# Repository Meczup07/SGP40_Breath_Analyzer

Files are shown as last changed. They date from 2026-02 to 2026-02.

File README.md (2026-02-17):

# 🌬️ SGP40-AlcSense: Ultra-Compact IoT Breathalyzer

  

**SGP40-AlcSense** is a portable, USB-C rechargeable breath analysis device (Breathalyzer) measuring only **30mm x 20mm**.

This project combines advanced **Sensirion SGP40 VOC** sensor technology with the power of the **Nordic nRF52832** SoC to measure alcohol intensity (VOC Index) and provide instant visual feedback via an RGB LED or transmit data to a mobile app via Bluetooth Low Energy (BLE).

---

## 📸 Project Images





---

## 🌟 Key Features

* **Ultra-Compact Design:** Keychain-sized (30x20mm) 2-layer PCB.
* **High-Sensitivity Detection:** Sensirion SGP40 MOx sensor sensitive to Alcohol (Ethanol) vapor.
* **Wireless Connectivity:** Bluetooth 5.0 (BLE) support via nRF52832 (ARM Cortex-M4F).
* **Visual Feedback:** RGB LED changes color based on ambient alcohol levels (Green/Yellow/Red).
* **Power Management:**
    * Integrated Li-Po Battery Charging Circuit (MCP73831).
    * DC-DC Buck Converter mode for low power consumption.
    * USB Type-C Charging Input.
* **RF Design:** Johanson 2450AT18A Chip Antenna with impedance matching (Pi-Network).

---

## 🛠️ Hardware Specifications

The project is built on the following core components:

| Component | Model | Description |
| :--- | :--- | :--- |
| **MCU** | `nRF52832-QFAA` | Main Processor & BLE Module. |
| **Sensor** | `SGP40-D-R4` | Digital VOC (Volatile Organic Compound) Sensor. |
| **Charger IC** | `MCP73831` | Li-Ion/Li-Po Charge Controller (CC/CV). |
| **Regulator** | `XC6206` | 3.3V LDO Voltage Regulator. |
| **Antenna** | `2450AT18A0110` | 2.4GHz SMD Chip Antenna. |
| **LED** | `XL-1608RGBC` | 0603 SMD RGB LED (Common Cathode). |
| **Connector** | `USB-C 16-Pin` | Power input & Charging. |

---

## 📐 Schematic & PCB Design

- **PCB Size:** 30mm x 20mm
- **Layers:** 2-layer PCB
- **Thickness:** 1.6mm
- **Design Tool:** Altium Designer / KiCAD

Full schematic and Gerber files are available in the [hardware/](hardware/) directory.

---

## 📌 Pinout Map

Pin definitions for firmware development:
```cpp
// RGB LED Connections (Common Cathode - Active LOW)
#define PIN_LED_RED    8   // P0.08
#define PIN_LED_GREEN  9   // P0.09
#define PIN_LED_BLUE   10  // P0.10

// I2C (SGP40 Sensor)
#define PIN_SDA        6   // P0.06 (check your schematic!)
#define PIN_SCL        7   // P0.07 (check your schematic!)

// SWD Programming Interface
#define PIN_SWDCLK     25  // P0.25
#define PIN_SWDIO      26  // P0.26

// Battery Monitoring (Optional)
#define PIN_VBAT_SENSE 3   // P0.03 (ADC Channel)
```

⚠️ **Important:** Verify pin assignments against your actual schematic before programming!

---

## 🚦 LED Status Indicators

The RGB LED provides real-time feedback on alcohol detection levels:

| VOC Index | LED Color | Status | Description |
|---|---|---|---|
| **0 - 100** | 🟢 Green | Safe | No alcohol detected |
| **100 - 250** | 🟡 Yellow | Moderate | Low alcohol level |
| **250+** | 🔴 Red | High | Dangerous alcohol level |

---

## 🔧 Software Development

### Prerequisites

Before building the firmware, you'll need:

1. **Segger Embedded Studio** (v7.22 or newer) - [Download](https://www.segger.com/downloads/embedded-studio/)
2. **Nordic nRF5 SDK v17.1.0** - [Download](https://www.nordicsemi.com/Products/Development-software/nrf5-sdk/download)
3. **J-Link Debugger** or **ST-Link V2** (for SWD programming)

---

### 📦 Step 1: Install nRF5 SDK

1. Download **nRF5 SDK v17.1.0** from Nordic's website:
```
   https://www.nordicsemi.com/Products/Development-software/nrf5-sdk/download
```

2. Extract the SDK to a convenient location:
   - **Windows:** `C:\nRF5_SDK_17.1.0`
   - **macOS/Linux:** `~/nRF5_SDK_17.1.0`

3. **Important:** Do NOT rename the SDK folder. Keep it as `nRF5_SDK_17.1.0`.

---

### 📥 Step 2: Clone This Repository
```bash
git clone https://github.com/Meczup07/SGP40_Breath_Analyzer.git
cd SGP40_Breath_Analyzer
```

---

### 🔨 Step 3: Build the Firmware

#### Option A: Using Segger Embedded Studio (Recommended)

1. Open Segger Embedded Studio

2. Navigate to the SDK example template:
```
   C:\nRF5_SDK_17.1.0\examples\ble_peripheral\ble_app_template\pca10040\s132\ses\
```

3. Open the project file:
```
   ble_app_template_pca10040_s132.emProject
```

4. In the **Project Explorer** (left panel), locate:
```
   Application → main.c
```

5. Replace the contents of `main.c` with the code from this repository's `src/main.c`

6. **Build the project:**
   - Press `F7` or go to **Build → Build Solution**

7. **Connect your J-Link debugger** to the SWD pins:
```
   J-Link    →    nRF52832
   --------       ---------
   SWDCLK   →    P0.25
   SWDIO    →    P0.26
   VDD      →    3.3V
   GND      →    GND
```

8. **Flash the firmware:**
   - Press `F5` or go to **Debug → Go**

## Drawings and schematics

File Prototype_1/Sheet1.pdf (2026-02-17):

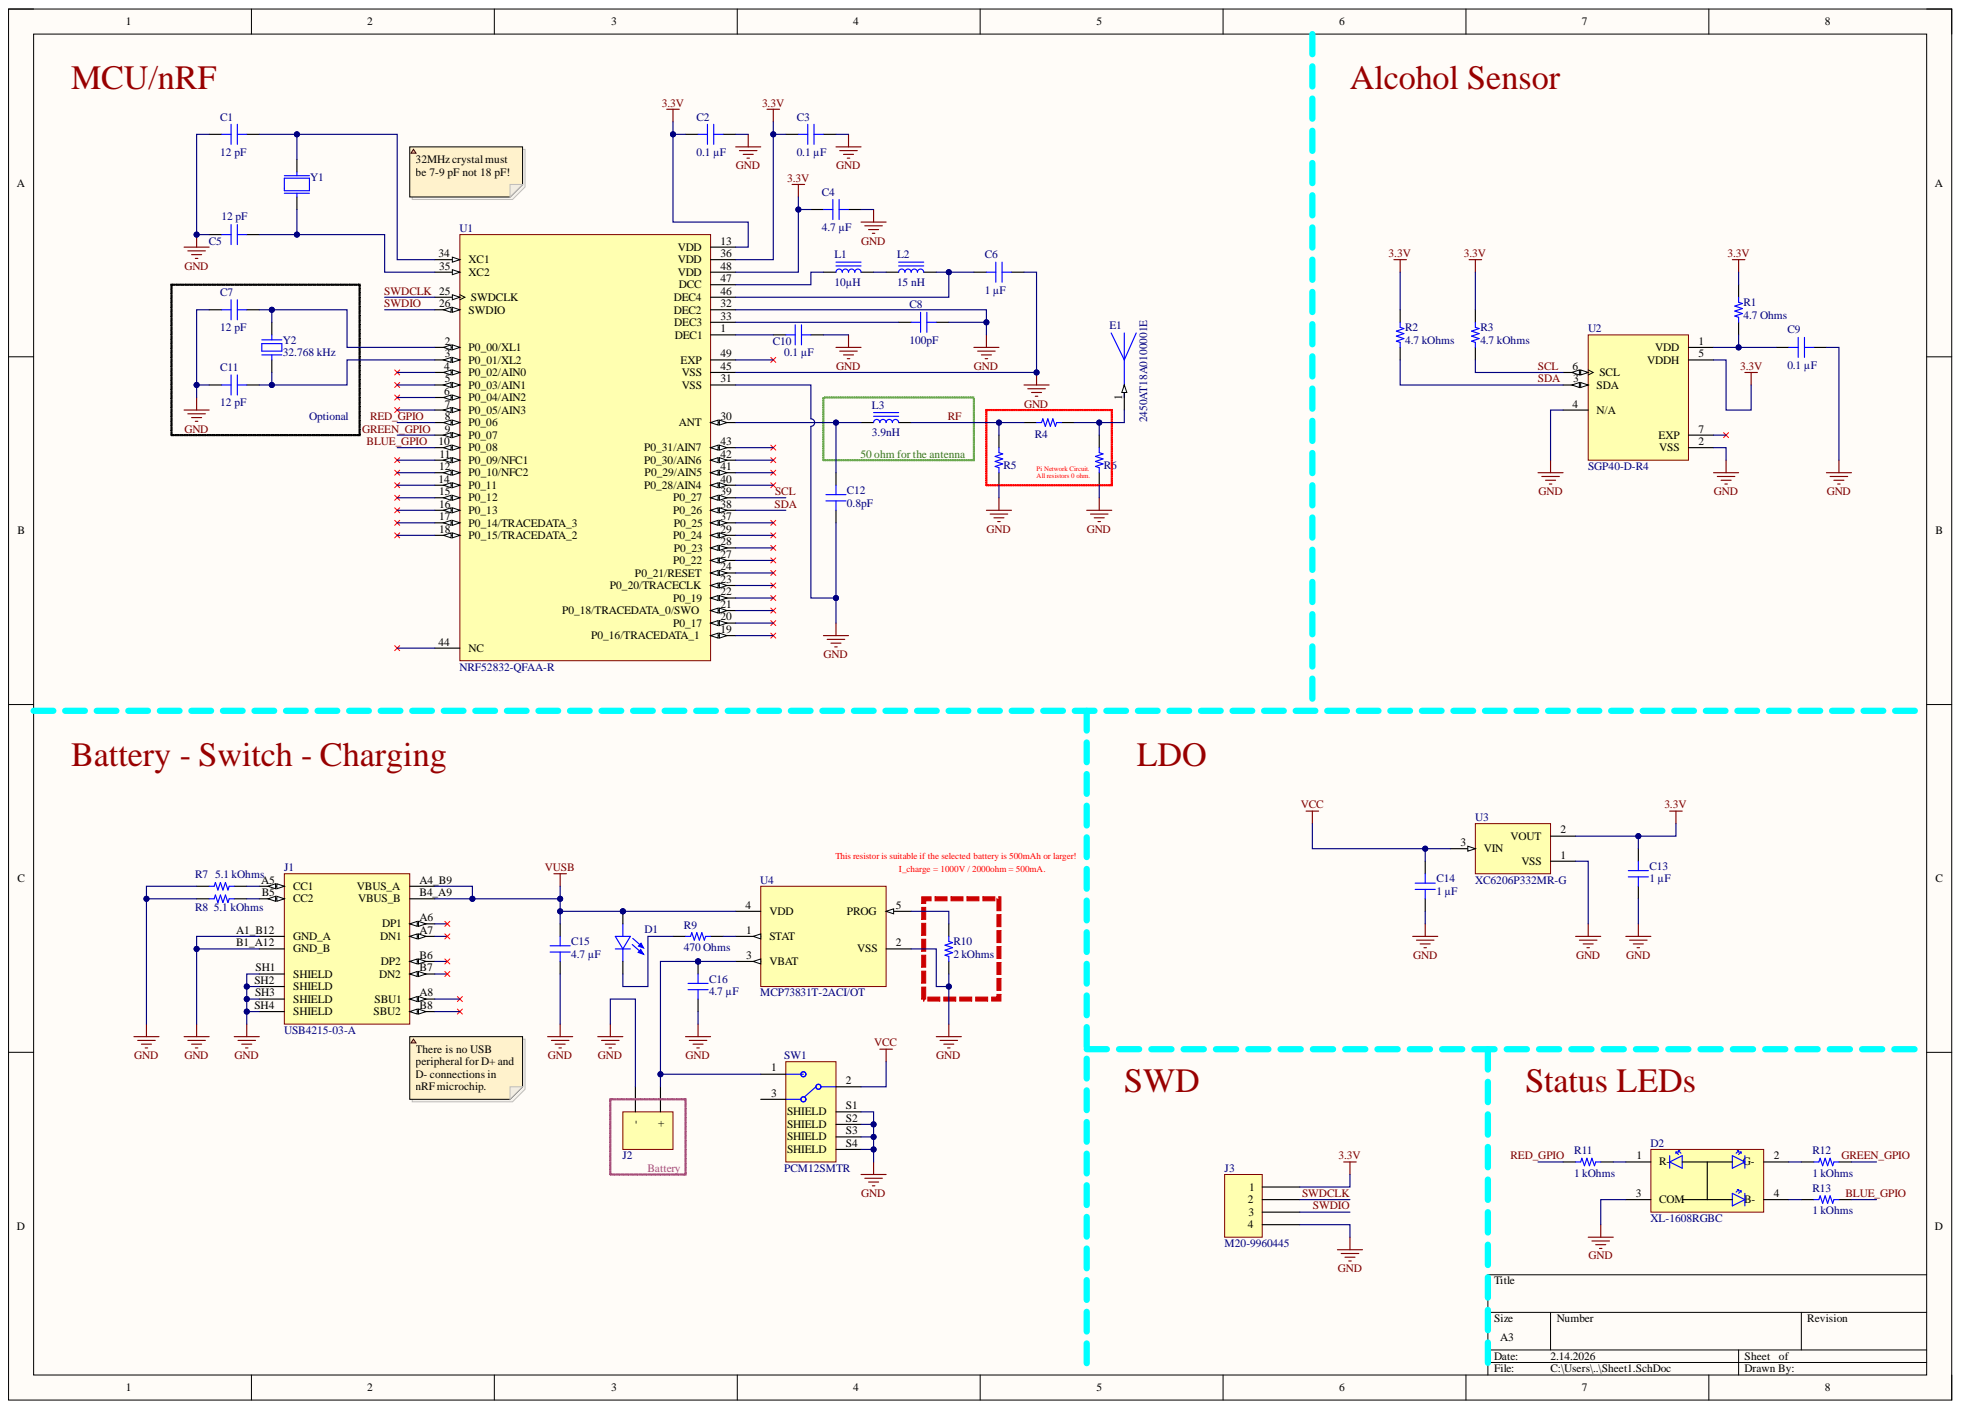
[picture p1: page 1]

32MHz crystal must
be 7-9 pF not 18 pF!

50 ohm for the antenna

Pi Network Circuit. All resistors 0 ohm.

This resistor is suitable if the selected battery is 500mAh or larger!

There is no USB
peripheral for D+ and
D- connections in
nRF microchip.

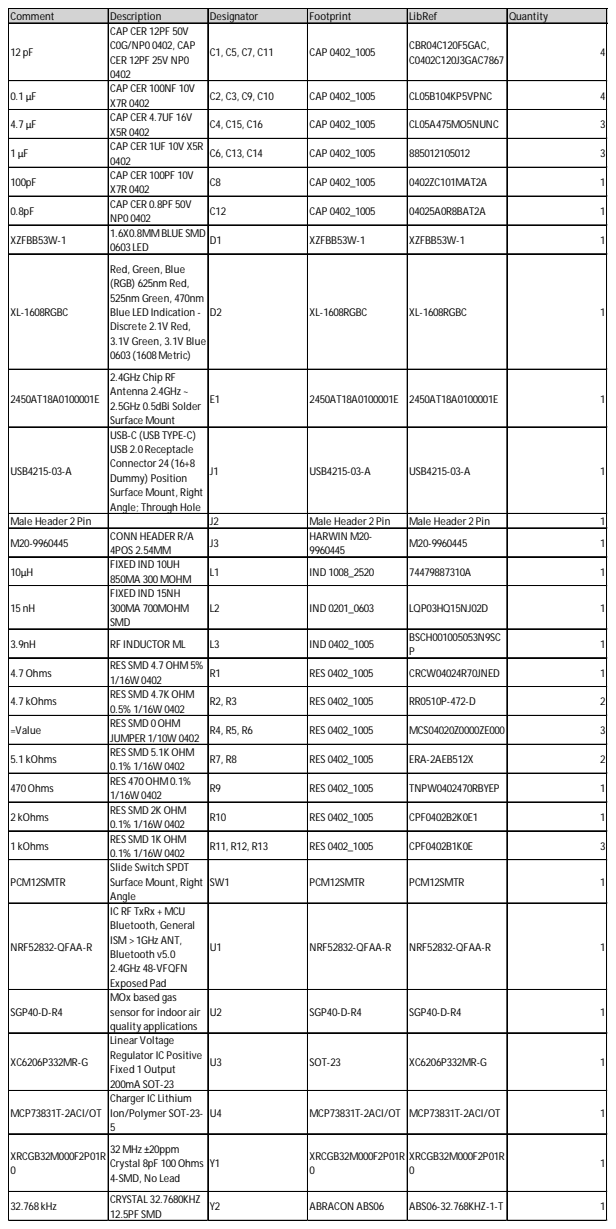
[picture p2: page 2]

Comment | Description | Designator | Footprint | LibRef | Quantity
12 pF | CAP CER 12PF 50V C0G/NP0 0402, CAP CER 12PF 25V NP0 0402 | C1, C5, C7, C11 | CAP 0402_1005 | CBR04C120F5GAC, C0402C120J3GAC7867 | 4

0.1 µF | CAP CER 100NF 10V X7R 0402 | C2, C3, C9, C10 | CAP 0402_1005 | CL05B104KP5VPNC | 4

4.7 µF | CAP CER 4.7UF 16V X5R 0402 | C4, C15, C16 | CAP 0402_1005 | CL05A475MO5NUNC | 3

1 µF | CAP CER 1UF 10V X5R 0402 | C6, C13, C14 | CAP 0402_1005 | 885012105012 | 3

100pF | CAP CER 100PF 10V X7R 0402 | C8 | CAP 0402_1005 | 0402ZC101MAT2A | 1

0.8pF | CAP CER 0.8PF 50V NP0 0402 | C12 | CAP 0402_1005 | 04025A0R8BAT2A | 1

XZFBB53W-1 | 1.6X0.8MM BLUE SMD 0603 LED | D1 | XZFBB53W-1 | XZFBB53W-1 | 1

XL-1608RGBC | Red, Green, Blue (RGB) 625nm Red, 525nm Green, 470nm Blue LED Indication -Discrete 2.1V Red, 3.1V Green, 3.1V Blue 0603 (1608 Metric) | D2 | XL-1608RGBC | XL-1608RGBC | 1

2450AT18A0100001E | 2.4GHz Chip RF Antenna 2.4GHz ~ 2.5GHz 0.5dBi Solder Surface Mount | E1 | 2450AT18A0100001E | 2450AT18A0100001E | 1

USB4215-03-A | USB-C (USB TYPE-C) USB 2.0 Receptacle Connector 24 (16+8 Dummy) Position Surface Mount, Right Angle; Through Hole | J1 | USB4215-03-A | USB4215-03-A | 1

Male Header 2 Pin | | J2 | Male Header 2 Pin | Male Header 2 Pin | 1
M20-9960445 | CONN HEADER R/A 4POS 2.54MM | J3 | HARWIN M20-9960445 | M20-9960445 | 1

10µH | FIXED IND 10UH 850MA 300 MOHM | L1 | IND 1008_2520 | 74479887310A | 1

15 nH | FIXED IND 15NH 300MA 700MOHM SMD | L2 | IND 0201_0603 | LQP03HQ15NJ02D | 1

3.9nH | RF INDUCTOR ML | L3 | IND 0402_1005 | BSCH001005053N9SC P | 1

4.7Ohms | RES SMD 4.7OHM 5% 1/16W 0402 | R1 | RES 0402_1005 | CRCW04024R70JNED | 1

4.7 kOhms | RES SMD 4.7K OHM 0.5% 1/16W 0402 | R2, R3 | RES 0402_1005 | RR0510P-472-D | 2

=Value | RES SMD 0OHM JUMPER 1/10W 0402 | R4, R5, R6 | RES 0402_1005 | MCS04020Z0000ZE000 | 3

5.1 kOhms | RES SMD 5.1K OHM 0.1% 1/16W 0402 | R7, R8 | RES 0402_1005 | ERA-2AEB512X | 2

470Ohms | RES 470OHM 0.1% 1/16W 0402 | R9 | RES 0402_1005 | TNPW0402470RBYEP | 1

2 kOhms | RES SMD 2K OHM 0.1% 1/16W 0402 | R10 | RES 0402_1005 | CPF0402B2K0E1 | 1

1 kOhms | RES SMD 1K OHM 0.1% 1/16W 0402 | R11, R12, R13 | RES 0402_1005 | CPF0402B1K0E | 3

PCM12SMTR | Slide Switch SPDT Surface Mount, Right Angle | SW1 | PCM12SMTR | PCM12SMTR | 1

NRF52832-QFAA-R | IC RF TxRx + MCU Bluetooth, General ISM > 1GHz ANT, Bluetooth v5.0 2.4GHz 48-VFQFN Exposed Pad | U1 | NRF52832-QFAA-R | NRF52832-QFAA-R | 1

SGP40-D-R4 | MOx based gas sensor for indoor air quality applications | U2 | SGP40-D-R4 | SGP40-D-R4 | 1

XC6206P332MR-G | Linear Voltage Regulator IC Positive Fixed 1Output 200mA SOT-23 | U3 | SOT-23 | XC6206P332MR-G | 1

MCP73831T-2ACI/OT | Charger IC Lithium Ion/Polymer SOT-23-5 | U4 | MCP73831T-2ACI/OT | MCP73831T-2ACI/OT | 1

XRCGB32M000F2P01R 0 | 32 MHz ±20ppm Crystal 8pF 100Ohms 4-SMD, No Lead | Y1 | XRCGB32M000F2P01R 0 | XRCGB32M000F2P01R 0 | 1

32.768 kHz | CRYSTAL 32.7680KHZ 12.5PF SMD | Y2 | ABRACON ABS06 | ABS06-32.768KHZ-1-T | 1

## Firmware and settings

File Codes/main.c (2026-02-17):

/**
 * Copyright (c) 2014 - 2021, Nordic Semiconductor ASA
 *
 * All rights reserved.
 *
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
 * 3. Neither the name of Nordic Semiconductor ASA nor the names of its
 *    contributors may be used to endorse or promote products derived from this
 *    software without specific prior written permission.
 *
 * 4. This software, with or without modification, must only be used with a
 *    Nordic Semiconductor ASA integrated circuit.
 *
 * 5. Any software provided in binary form under this license must not be reverse
 *    engineered, decompiled, modified and/or disassembled.
 *
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
 */
/** @file
 *
 * @defgroup ble_sdk_app_template_main main.c
 * @{
 * @ingroup ble_sdk_app_template
 * @brief Template project main file.
 *
 * This file contains a template for creating a new application. It has the code necessary to wakeup
 * from button, advertise, get a connection restart advertising on disconnect and if no new
 * connection created go back to system-off mode.
 * It can easily be used as a starting point for creating a new application, the comments identified
 * with 'YOUR_JOB' indicates where and how you can customize.
 */

#include <stdbool.h>
#include <stdint.h>
#include <string.h>

#include "nordic_common.h"
#include "nrf.h"
#include "app_error.h"
#include "ble.h"
#include "ble_hci.h"
#include "ble_srv_common.h"
#include "ble_advdata.h"
#include "ble_advertising.h"
#include "ble_conn_params.h"
#include "nrf_sdh.h"
#include "nrf_sdh_soc.h"
#include "nrf_sdh_ble.h"
#include "app_timer.h"
#include "nrf_ble_gatt.h"
#include "nrf_ble_qwr.h"
#include "nrf_pwr_mgmt.h"
#include "nrf_drv_twi.h"
#include "nrf_gpio.h"
#include "nrf_delay.h"
#include "nrf_log.h"
#include "nrf_log_ctrl.h"
#include "nrf_log_default_backends.h"

#define RED_LED_PIN      6 
#define GREEN_LED_PIN    7 
#define BLUE_LED_PIN     8

#define SCL_PIN          27
#define SDA_PIN          26

// SGP40 I2C Adresi
#define SGP40_I2C_ADDR  0x59

// Alkol Eşikleri (VOC index değerleri)
#define SAFE_THRESHOLD      100
#define MODERATE_THRESHOLD  250

// BLE (Blueetooth Low Energy) Ayarları
#define DEVICE_NAME                     "Breath_Analyzerr"
#define APP_BLE_OBSERVER_PRIO           3
#define APP_BLE_CONN_CFG_TAG            1
#define APP_ADV_INTERVAL                300

#define APP_ADV_DURATION                18000
#define MIN_CONN_INTERVAL               MSEC_TO_UNITS(100, UNIT_1_25_MS)
#define MAX_CONN_INTERVAL               MSEC_TO_UNITS(200, UNIT_1_25_MS)
#define SLAVE_LATENCY                   0
#define CONN_SUP_TIMEOUT                MSEC_TO_UNITS(4000, UNIT_10_MS)

#define FIRST_CONN_PARAMS_UPDATE_DELAY  APP_TIMER_TICKS(5000)
#define NEXT_CONN_PARAMS_UPDATE_DELAY   APP_TIMER_TICKS(30000)
#define MAX_CONN_PARAMS_UPDATE_COUNT    3

// Custom Service UUID'ler
#define ALCOHOL_SERVICE_UUID_BASE  {0x23, 0xD1, 0xBC, 0xEA, 0x5F, 0x78, 0x23, 0x15, \
                                     0xDE, 0xEF, 0x12, 0x12, 0x00, 0x00, 0x00, 0x00}
#define ALCOHOL_SERVICE_UUID       0x1815
#define ALCOHOL_CHAR_UUID          0x2A56

NRF_BLE_GATT_DEF(m_gatt);                                                       /**< GATT module instance. */
NRF_BLE_QWR_DEF(m_qwr);                                                         /**< Context for the Queued Write module.*/
BLE_ADVERTISING_DEF(m_advertising);                                             /**< Advertising module instance. */

static uint16_t m_conn_handle = BLE_CONN_HANDLE_INVALID;                        /**< Handle of the current connection. */
static uint16_t m_service_handle;
static ble_gatts_char_handles_t m_char_handles;

// I2C
static const nrf_drv_twi_t m_twi = NRF_DRV_TWI_INSTANCE(0); //?
static volatile bool m_xfer_done = false;

// Timer
APP_TIMER_DEF(m_measurement_timer_id);
#define MEASUREMENT_INTERVAL        APP_TIMER_TICKS(1000)

/**@brief TWI event handler. */
void twi_handler(nrf_drv_twi_evt_t const * p_event, void * p_context)
{
    switch (p_event->type)
    {
        case NRF_DRV_TWI_EVT_DONE:
            m_xfer_done = true;
            break;
        default:
            break;
    }
}

/**@brief TWI initialization. */
void twi_init(void)
{
    ret_code_t err_code;

    const nrf_drv_twi_config_t twi_config = {
       .scl                = SCL_PIN,
       .sda                = SDA_PIN,
       .frequency          = NRF_DRV_TWI_FREQ_100K,
       .interrupt_priority = APP_IRQ_PRIORITY_HIGH,
       .clear_bus_init     = false
    };

    err_code = nrf_drv_twi_init(&m_twi, &twi_config, twi_handler, NULL);
    APP_ERROR_CHECK(err_code);

    nrf_drv_twi_enable(&m_twi);
    
    NRF_LOG_INFO("TWI initialized.");
}

/**@brief SGP40'tan veri okuma */
uint16_t read_sgp40_voc(void)
{
    ret_code_t err_code;
    uint8_t cmd[2] = {0x26, 0x0F}; // Measure Raw Signal
    uint8_t data[3];
    
    // Komutu gönder
    m_xfer_done = false;
    err_code = nrf_drv_twi_tx(&m_twi, SGP40_I2C_ADDR, cmd, sizeof(cmd), true);
    if (err_code != NRF_SUCCESS)
    {
        NRF_LOG_ERROR("TWI TX error: %d", err_code);
        return 0;
    }
    
    while (m_xfer_done == false);
    
    // Sensörün ölçüm yapması için bekle
    nrf_delay_ms(30);
    
    // Veriyi oku
    m_xfer_done = false;
    err_code = nrf_drv_twi_rx(&m_twi, SGP40_I2C_ADDR, data, sizeof(data));
    if (err_code != NRF_SUCCESS)
    {
        NRF_LOG_ERROR("TWI RX error: %d", err_code);
        return 0;
    }
    
    while (m_xfer_done == false);
    
    // Ham sinyal değeri
    uint16_t raw_signal = (data[0] << 8) | data[1];
    // CRC: data[2] (kontrol etmiyoruz şimdilik)
    
    // Ham sinyali VOC index'e dönüştür (basitleştirilmiş)
    // Gerçek uygulamada Sensirion'un VOC Algorithm kullanılmalı
    int32_t voc_index = (raw_signal - 20000) / 60;
    if (voc_index < 0) voc_index = 0;
    if (voc_index > 500) voc_index = 500;
    
    return (uint16_t)voc_index;
}

/**@brief RGB LED kontrolü */
void set_rgb_led(bool red, bool green, bool blue)
{
    // XL-1608RGBC common cathode LED
    // 0 = LED yanık, 1 = LED sönük (common cathode için)
    nrf_gpio_pin_write(RED_LED_PIN, red ? 0 : 1);
    nrf_gpio_pin_write(GREEN_LED_PIN, green ? 0 : 1);
    nrf_gpio_pin_write(BLUE_LED_PIN, blue ? 0 : 1);
}

/**@brief Alkol seviyesine göre LED güncelle */
void update_led_status(uint16_t voc_index)
{
    if (voc_index < SAFE_THRESHOLD)
    {
        // Yeşil - Güvenli
        set_rgb_led(false, true, false);
        NRF_LOG_INFO("Durum: GUVENLI (Yesil) - VOC: %d", voc_index);
    }
    else if (voc_index < MODERATE_THRESHOLD)
    {
        // Sarı - Orta (Kırmızı + Yeşil)
        set_rgb_led(true, true, false);
        NRF_LOG_WARNING("Durum: ORTA (Sari) - VOC: %d", voc_index);
    }
    else
    {
        // Kırmızı - Tehlikeli
        set_rgb_led(true, false, false);
        NRF_LOG_ERROR("Durum: TEHLIKELI (Kirmizi) - VOC: %d", voc_index);
    }
}

/**@brief Function for handling BLE events. */
static void ble_evt_handler(ble_evt_t const * p_ble_evt, void * p_context)
{
    ret_code_t err_code;

    switch (p_ble_evt->header.evt_id)
    {
        case BLE_GAP_EVT_CONNECTED:
            NRF_LOG_INFO("Connected");
            m_conn_handle = p_ble_evt->evt.gap_evt.conn_handle;
            err_code = nrf_ble_qwr_conn_handle_assign(&m_qwr, m_conn_handle);
            APP_ERROR_CHECK(err_code);
            break;

        case BLE_GAP_EVT_DISCONNECTED:
            NRF_LOG_INFO("Disconnected");
            m_conn_handle = BLE_CONN_HANDLE_INVALID;
            break;

        case BLE_GAP_EVT_PHY_UPDATE_REQUEST:
        {
            NRF_LOG_DEBUG("PHY update request.");
            ble_gap_phys_t const phys =
            {
                .rx_phys = BLE_GAP_PHY_AUTO,
                .tx_phys = BLE_GAP_PHY_AUTO,
            };
            err_code = sd_ble_gap_phy_update(p_ble_evt->evt.gap_evt.conn_handle, &phys);
            APP_ERROR_CHECK(err_code);
        } break;

        case BLE_GATTC_EVT_TIMEOUT:
            NRF_LOG_DEBUG("GATT Client Timeout.");
            err_code = sd_ble_gap_disconnect(p_ble_evt->evt.gattc_evt.conn_handle,
                                             BLE_HCI_REMOTE_USER_TERMINATED_CONNECTION);
            APP_ERROR_CHECK(err_code);
            break;

        case BLE_GATTS_EVT_TIMEOUT:
            NRF_LOG_DEBUG("GATT Server Timeout.");
            err_code = sd_ble_gap_disconnect(p_ble_evt->evt.gatts_evt.conn_handle,
                                             BLE_HCI_REMOTE_USER_TERMINATED_CONNECTION);
            APP_ERROR_CHECK(err_code);
            break;

        default:
            break;
    }
}

/**@brief Function for initializing the BLE stack. */
static void ble_stack_init(void)
{
    ret_code_t err_code;

    err_code = nrf_sdh_enable_request();
    APP_ERROR_CHECK(err_code);

    uint32_t ram_start = 0;
    err_code = nrf_sdh_ble_default_cfg_set(APP_BLE_CONN_CFG_TAG, &ram_start);
    APP_ERROR_CHECK(err_code);

    err_code = nrf_sdh_ble_enable(&ram_start);
    APP_ERROR_CHECK(err_code);

    NRF_SDH_BLE_OBSERVER(m_ble_observer, APP_BLE_OBSERVER_PRIO, ble_evt_handler, NULL);
}

/**@brief Function for the GAP initialization. */
static void gap_params_init(void)
{
    ret_code_t              err_code;
    ble_gap_conn_params_t   gap_conn_params;
    ble_gap_conn_sec_mode_t sec_mode;

    BLE_GAP_CONN_SEC_MODE_SET_OPEN(&sec_mode);

    err_code = sd_ble_gap_device_name_set(&sec_mode,
                                          (const uint8_t *)DEVICE_NAME,
                                          strlen(DEVICE_NAME));
    APP_ERROR_CHECK(err_code);

    memset(&gap_conn_params, 0, sizeof(gap_conn_params));

    gap_conn_params.min_conn_interval = MIN_CONN_INTERVAL;
    gap_conn_params.max_conn_interval = MAX_CONN_INTERVAL;
    gap_conn_params.slave_latency     = SLAVE_LATENCY;
    gap_conn_params.conn_sup_timeout  = CONN_SUP_TIMEOUT;

    err_code = sd_ble_gap_ppcp_set(&gap_conn_params);
    APP_ERROR_CHECK(err_code);
}

/**@brief Function for initializing the GATT module. */
static void gatt_init(void)
{
    ret_code_t err_code = nrf_ble_gatt_init(&m_gatt, NULL);
    APP_ERROR_CHECK(err_code);
}

/**@brief Function for handling Queued Write Module errors. */
static void nrf_qwr_error_handler(uint32_t nrf_error)
{
    APP_ERROR_HANDLER(nrf_error);
}

/**@brief Function for initializing services. */
static void services_init(void)
{
    ret_code_t         err_code;
    nrf_ble_qwr_init_t qwr_init = {0};

    qwr_init.error_handler = nrf_qwr_error_handler;

    err_code = nrf_ble_qwr_init(&m_qwr, &qwr_init);
    APP_ERROR_CHECK(err_code);

    // Custom Alcohol Service ekle
    ble_uuid_t        service_uuid;
    ble_uuid128_t     base_uuid = ALCOHOL_SERVICE_UUID_BASE;

    service_uuid.uuid = ALCOHOL_SERVICE_UUID;
    err_code = sd_ble_uuid_vs_add(&base_uuid, &service_uuid.type);
    APP_ERROR_CHECK(err_code);

    err_code = sd_ble_gatts_service_add(BLE_GATTS_SRVC_TYPE_PRIMARY,
                                        &service_uuid,
                                        &m_service_handle);
    APP_ERROR_CHECK(err_code);

    // Characteristic ekle
    ble_gatts_char_md_t char_md;
    ble_gatts_attr_md_t cccd_md;
    ble_gatts_attr_t    attr_char_value;
    ble_uuid_t          char_uuid;
    ble_gatts_attr_md_t attr_md;

    memset(&cccd_md, 0, sizeof(cccd_md));
    BLE_GAP_CONN_SEC_MODE_SET_OPEN(&cccd_md.read_perm);
    BLE_GAP_CONN_SEC_MODE_SET_OPEN(&cccd_md.write_perm);
    cccd_md.vloc = BLE_GATTS_VLOC_STACK;

    memset(&char_md, 0, sizeof(char_md));
    char_md.char_props.read   = 1;
    char_md.char_props.notify = 1;
    char_md.p_cccd_md         = &cccd_md;

    char_uuid.uuid = ALCOHOL_CHAR_UUID;
    char_uuid.type = service_uuid.type;

    memset(&attr_md, 0, sizeof(attr_md));
    BLE_GAP_CONN_SEC_MODE_SET_OPEN(&attr_md.read_perm);
    attr_md.vloc    = BLE_GATTS_VLOC_STACK;
    attr_md.rd_auth = 0;
    attr_md.wr_auth = 0;
    attr_md.vlen    = 0;

    memset(&attr_char_value, 0, sizeof(attr_char_value));
    attr_char_value.p_uuid    = &char_uuid;
    attr_char_value.p_attr_md = &attr_md;
    attr_char_value.init_len  = sizeof(uint16_t);
    attr_char_value.init_offs = 0;
    attr_char_value.max_len   = sizeof(uint16_t);

    err_code = sd_ble_gatts_characteristic_add(m_service_handle,
                                               &char_md,
                                               &attr_char_value,
                                               &m_char_handles);
    APP_ERROR_CHECK(err_code);

    NRF_LOG_INFO("Alcohol Service initialized.");
}

/**@brief Function for handling the Connection Parameters Module. */
static void on_conn_params_evt(ble_conn_params_evt_t * p_evt)
{
    ret_code_t err_code;

    if (p_evt->evt_type == BLE_CONN_PARAMS_EVT_FAILED)
    {
        err_code = sd_ble_gap_disconnect(m_conn_handle, BLE_HCI_CONN_INTERVAL_UNACCEPTABLE);
        APP_ERROR_CHECK(err_code);
    }
}

/**@brief Function for handling a Connection Parameters error. */
static void conn_params_error_handler(uint32_t nrf_error)
{
    APP_ERROR_HANDLER(nrf_error);
}

/**@brief Function for initializing the Connection Parameters module. */
static void conn_params_init(void)
{
    ret_code_t             err_code;
    ble_conn_params_init_t cp_init;

    memset(&cp_init, 0, sizeof(cp_init));

    cp_init.p_conn_params                  = NULL;
    cp_init.first_conn_params_update_delay = FIRST_CONN_PARAMS_UPDATE_DELAY;
    cp_init.next_conn_params_update_delay  = NEXT_CONN_PARAMS_UPDATE_DELAY;
    cp_init.max_conn_params_update_count   = MAX_CONN_PARAMS_UPDATE_COUNT;
    cp_init.start_on_notify_cccd_handle    = BLE_GATT_HANDLE_INVALID;
    cp_init.disconnect_on_fail             = false;
    cp_init.evt_handler                    = on_conn_params_evt;
    cp_init.error_handler                  = conn_params_error_handler;

    err_code = ble_conn_params_init(&cp_init);
    APP_ERROR_CHECK(err_code);
}

/**@brief Function for handling advertising events. */
static void on_adv_evt(ble_adv_evt_t ble_adv_evt)
{
    switch (ble_adv_evt)
    {
        case BLE_ADV_EVT_FAST:
            NRF_LOG_INFO("Fast advertising.");
            break;
        case BLE_ADV_EVT_IDLE:
            break;
        default:
            break;
    }
}

/**@brief Function for initializing the Advertising functionality. */
static void advertising_init(void)
{
    ret_code_t             err_code;
    ble_advertising_init_t init;

    memset(&init, 0, sizeof(init));

    init.advdata.name_type               = BLE_ADVDATA_FULL_NAME;
    init.advdata.include_appearance      = false;
    init.advdata.flags                   = BLE_GAP_ADV_FLAGS_LE_ONLY_GENERAL_DISC_MODE;

    init.config.ble_adv_fast_enabled  = true;
    init.config.ble_adv_fast_interval = APP_ADV_INTERVAL;
    init.config.ble_adv_fast_timeout  = APP_ADV_DURATION;

    init.evt_handler = on_adv_evt;

    err_code = ble_advertising_init(&m_advertising, &init);
    APP_ERROR_CHECK(err_code);

    ble_advertising_conn_cfg_tag_set(&m_advertising, APP_BLE_CONN_CFG_TAG);
}

/**@brief Function for initializing the nrf log module. */
static void log_init(void)
{
    ret_code_t err_code = NRF_LOG_INIT(NULL);
    APP_ERROR_CHECK(err_code);

    NRF_LOG_DEFAULT_BACKENDS_INIT();
}

/**@brief Function for initializing power management. */
static void power_management_init(void)
{
    ret_code_t err_code;
    err_code = nrf_pwr_mgmt_init();
    APP_ERROR_CHECK(err_code);
}

/**@brief Function for handling the idle state (main loop). */
static void idle_state_handle(void)
{
    if (NRF_LOG_PROCESS() == false)
    {
        nrf_pwr_mgmt_run();
    }
}

/**@brief Function for starting advertising. */
static void advertising_start(void)
{
    ret_code_t err_code = ble_advertising_start(&m_advertising, BLE_ADV_MODE_FAST);
    APP_ERROR_CHECK(err_code);
}

/**@brief GPIO initialization. */
static void gpio_init(void)
{
    nrf_gpio_cfg_output(RED_LED_PIN);
    nrf_gpio_cfg_output(GREEN_LED_PIN);
    nrf_gpio_cfg_output(BLUE_LED_PIN);

    set_rgb_led(false, false, false); // Başlangıçta tüm LED'ler kapalı
}

/**@brief Timer handler for measurements. */
static void measurement_timer_handler(void * p_context)
{
    UNUSED_PARAMETER(p_context);

    // SGP40'tan VOC değerini oku
    uint16_t voc_index = read_sgp40_voc();

    // LED durumunu güncelle
    update_led_status(voc_index);

    // BLE üzerinden gönder (bağlıysa)
    if (m_conn_handle != BLE_CONN_HANDLE_INVALID)
    {
        ble_gatts_hvx_params_t hvx_params;
        uint16_t len = sizeof(voc_index);

        memset(&hvx_params, 0, sizeof(hvx_params));

        hvx_params.handle = m_char_handles.value_handle;
        hvx_params.type   = BLE_GATT_HVX_NOTIFICATION;
        hvx_params.offset = 0;
        hvx_params.p_len  = &len;
        hvx_params.p_data = (uint8_t *)&voc_index;

        ret_code_t err_code = sd_ble_gatts_hvx(m_conn_handle, &hvx_params);
        if (err_code == NRF_SUCCESS)
        {
            NRF_LOG_INFO("VOC data sent via BLE: %d", voc_index);
        }
    }
}

/**@brief Function for initializing the timer module. */
static void timers_init(void)
{
    ret_code_t err_code = app_timer_init();
    APP_ERROR_CHECK(err_code);

    err_code = app_timer_create(&m_measurement_timer_id,
                                APP_TIMER_MODE_REPEATED,
                                measurement_timer_handler);
    APP_ERROR_CHECK(err_code);
}

/**@brief Function for starting timers. */
static void application_timers_start(void)
{
    ret_code_t err_code;

    err_code = app_timer_start(m_measurement_timer_id, MEASUREMENT_INTERVAL, NULL);
    APP_ERROR_CHECK(err_code);
}

/**@brief Application main function. */
int main(void)
{
    // Initialize.
    log_init();
    timers_init();
    power_management_init();
    gpio_init();
    twi_init();
    ble_stack_init();
    gap_params_init();
    gatt_init();
    services_init();
    advertising_init();
    conn_params_init();

    // Start execution.
    NRF_LOG_INFO("Alkol Olcer Application started.");
    application_timers_start();
    advertising_start();

    // Enter main loop.
    for (;;)
    {
        idle_state_handle();
    }


/**
 * @}
 */

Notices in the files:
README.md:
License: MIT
